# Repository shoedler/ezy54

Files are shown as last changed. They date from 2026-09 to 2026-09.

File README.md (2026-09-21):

> [!CAUTION]
> This is a WIP - this keyboard has not been built yet.

# ezy54
A 54-key, column-staggered, ortholinear, wireless split keyboard, inspired by ZSA Voyager and totem.
Designed for Choc-spacing (18mm horizontal, 17mm vertical) and 1350 Choc v1 or v2 switches.

---

## Bill of materials

For one complete board - e.g. two halves - you'll need:

- 2 Promicro NRF52840
- 54 1N4148W SOD-123 Diodes
- 54 Kailh Low-profile 1350 Hotswap Sockets
- 54 Keyswitches, Choc v1 or v2
- 54 Choc-spaced Keycaps, Choc v1 or v2 stems
- 2 EVQPUL02K Switches ($\to$ board reset button)
- 2 SSSS811101 Switches ($\to$ power switch)
- 2 701535 3.7v, 350mAh
- 2 JST PH 2.0 THT Sockets

For the case you'll need:

- Obviously, the printed case files. See section about printing below.
- 10x M2x5 (or 6)mm flathead screws
- 10x M2x3mm Heat set inserts
- Optionally, some painters tape.

## Build guide

### PCB manufacturing

> PCB related files are located in the `kicad` directory.

Assuming you have ordered the parts and don't want to route the PCB yourself, there's premade gerber archive located at `kicad/gerber.zip` which you can use. I've used JLCPCB, default settings (1.6mm two layer PCB) and with the black solder mask.

### Printing the case

> Case files are located in the `stl` directory.

I used a Babulab A1 mini and default slicer settings (Bambustudio). Everything was printed in their PLA Matte.

#### What do I need to print?

You'll need at least:

- 2x `ezy54_switchplate_right.stl`, which is the plate that sits on the PCB and where the keyswitches are mounted into - I recommend using the provided 3mf files for that: `ezy54_switchplate_left.3mf` and `ezy54_switchplate_right.3mf`. That'll give you mirrored versions so you have the buildplate-finish texture on the same side for both halves.
- 2x `ezy54_case_left.stl`, which is the case where the PCB gets mounted in - same story, use the provided 3mf files for that: `ezy54_case_left.3mf` and `ezy54_case_right.3mf`. That'll also give you mirrored versions for both halves with fuzzy skin. Theoretically, you don't **need** the case, but I strongly recommend it to provide a little bit of protection for the PCB. If you're working directly with the stl, then you'll have to mirror it. I suggest using the fuzzy skin setting (in Bambustudio: `Others > Special mode > Fuzzy skin`, use "Contour").

Optional:

- 2x `ezy54_case_cover_right.stl`, which is a small cover for the MCU + battery. Use `ezy54_case_cover_left.3mf` and `ezy54_case_cover_right.3mf` for mirrored version. Same as with the case, if you're working with the stl directly you'll need to mirror this too.
- 1x `ezy54_carry_case.stl`, which is a Go60-ish carry shell for the ezy54. Use `ezy54_carry_case.3mf` for a version with fuzzy skin. I did manage to print it without support, but there's a bit of luck involved.

### Soldering

Since the PCB is reversible it can get confusing quick. All of the components **except the ProMicro and the JST connector** are soldered to the backside of each half.

1. Solder diodes, hotswap sockets, reset- and powerswitches on the backside of each half. **This is also the side were you bridge all of the solder-jumpers with solder** (8 for the Mcu, 2 for the Battery connector).
2. Direct-solder the ProMicro to the frontside of the PCB, along with the JST connector. (Pin Sockets are also an option for the mcu, if you want - it just makes the keyboard a bit thicker)

> [!CAUTION]
> Before you continue it's a good idea to verify that there's no short between the JSTs +/- terminal as well as the ProMicros VCC and GND.

I suggest to load the firmware next and check that everything works before assembly.

### Loading the ZMK firmware

> Firmware related files consist of: config/, boards/, zephyr/ directories, as well as the build.yml file and the GitHub Actions workflow in .github/workflows.build.yml

Get the latest firmware from https://github.com/shoelder/ezy54/actions, select the latest run and scroll down to Artifacts - you'll be able to download the zip archive from there.

> [!NOTE]
> There'll be two .uf2 files per half in the zip archive - a `de-ch` and an `en` version. This refers to the keycode locale that's been used. I myself require a swiss locale, but, to make the default firmware more useful for more people, I've added an english version too. You can check the keymaps out in the `config/boards/shields/ezy54` directory.

For each half:

1. Plug in the half to your device using a USB cable.
2. Press the reset button twice within 500ms - on my versions of the ProMicro, their red LED breaths gently once you've entered bootloader mode.
3. You'll see a `NICENANO` appear in your device tree. Simply drag and drop the **correct** firmware for the half your working on onto the mcu - it should eject itself automatically once the firmware is flashed.

> [!NOTE]
> If you run into trouble, there's also a `settings_reset` firmware provided in the archive. See [the ZMK troubleshooting guide](https://zmk.dev/docs/troubleshooting/connection-issues#reset-split-keyboard-procedure) on how to flash it.

### Assembly

1. Prep the cases by installing the heat set inserts.
2. Cover the bottom sides of the PCBs with tape (I used masking tape). Apply the first layer quite firmly, such that it follows the contours of the hotswap sockets. You'll want to make sure that you extend the tape over the edges of the PCB. Apply at least 3 layers. In my experience anything beyond 5 layers of standard painters tape yields no further improvements. Also, it gets thick quick.
3. Trace the PCB outline to the tape with a pen. Also, trace the screw holes.
4. Remove the tape, and cut out the shape - make sure to inset the cut about 2-3mm, so the tape is not visible when everything is assembled. For the screw holes, cut a ~5x5mm square. Apply the tape.
5. Assemble both halves.
6. Install the switches, caps and the battery. For the battery, I usually use a thin, clear double-sided tape. Done!

---

## Modifying the ergogen config

The whole point of using ergogen, is to easily adapt the PCB to your liking. So give it a go!
Modifying the config will force you to reroute the PCB again. Though fear not - using [Freerouting](www.freerouting.app) this literally takes a minute to do (including adding freerouting to KiCad), provided you have KiCad >=8 and JRE >= 17 for Freerouting already installed.

> [!NOTE]
> To add the Freerouting KiCad integration, just follow [this](https://github.com/freerouting/freerouting/blob/master/docs/integrations.md) official guide.

> [!TIP]
> There is a local toolchain in [`tools/`](tools/README.md) that builds the config without
> ergogen.xyz and then checks it: case clearances, a pre-routing DRC on the generated board,
> STL/cross-section/point-probe inspection of the printed parts, and layered drawings. Start
> with `cd tools && npm run setup`, then `node tools/build.ts` and
> `node tools/drc-lite.ts out/pcbs/ezy54.kicad_pcb`. Its README also documents the
> footprint rotation convention that ergogen + KiCad make easy to get backwards.

1. Paste `config.yml` located in `/ergogen` into [ergogen.xyz](ergogen.xyz) and download the `ezy54.kicad_pcb` file.
2. Copy (and overwrite) `ezy54.kicad_pcb` to the `kicad` directory of this repository *(this part is only required if you intend to keep the source of this repository up to date - e.g. if you forked this)*
3. Open the PCB in KiCad (Standalone PCB editor suffices). Press `B` to fill the GND pours - zones come out of ergogen empty until KiCad calculates them once - then click on `Tools > External Plugins > Freerouting`
4. Let it rip. In my experience, the defaults of Freerouting suffice.

> [!IMPORTANT]
> Back in KiCad, run the DRC in `Inspect > Design Rule Checker`. I usually right click `> Ignore all 'Footprint not found in libraries' violations` to ignore missing ceoloide footprint warnings. This might leave you with some warnings which you need to manually resolve. For example, i usually get "Track has unconnected end", which is easily resolved by deleting the stub.

5. `File > Plot... > Generate Drill Files`, name the folder "gerber", then press `Generate` and close that popup. Press `Plot` back in the plot dialog. Done!

## References

- Flatfootfox' detailed design guide: https://flatfootfox.com/ergogen-part1-units-points/
- nickcoutsos Keymap-editor: https://nickcoutsos.github.io/keymap-editor/
- nickcoutsos Keymap-layout-tools: https://nickcoutsos.github.io/keymap-layout-tools/
- Joel Spadins zmk-locale-generator for the de-swiss keycode header: https://github.com/joelspadin/zmk-locale-generator
- ZMK guide on how to add a new shield: https://zmk.dev/docs/development/hardware-integration/new-shield
- More of my keyboards:
  - effiddy - a 50-key wireless split, inspired by totem: https://github.com/shoedler/effiddy
  - shoedler54 - a 54-key wireless split, inspired by ZSA Voyager and silakka54: https://github.com/shoedler/shoedler54

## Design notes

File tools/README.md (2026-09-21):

# ezy54 tooling

Local build + verification for `ergogen/config.yml`. The point is to be able to
change a unit and immediately see whether the PCB, the switchplate, the bottom
case and the carry case are all still sane — without pasting into ergogen.xyz
and eyeballing it.

Everything here is optional: the config is still a plain ergogen config you can
paste into <https://ergogen.xyz>.

## Setup

Needs **Node 22.18+** (for running TypeScript without a build step) and
**git**. Then:

```bash
cd tools && npm run setup
```

That installs the node dependencies and clones
[ceoloide/ergogen-footprints](https://github.com/ceoloide/ergogen-footprints)
into `tools/vendor/` (gitignored — it carries its own licence).

The tools are TypeScript and run directly: `node tools/check.ts`, no build, no
`dist/`. `npm --prefix tools run typecheck` runs `tsc --noEmit` over them, and
`npm --prefix tools test` runs the unit tests.

## Build

```bash
node tools/build.ts
```

Writes `out/` — `outlines/`, `cases/`, `pcbs/ezy54.kicad_pcb`, and (because it
runs ergogen in debug mode) `points/points.yaml` + `points/units.yaml`, which
every check below reads.

## Checks

### `node tools/check.ts out`

Geometric assertions on the case: that the MCU/battery housing is inside the
board outline, the cavity inside the housing, the screw bosses inside the
cavity, the battery and connector inside the cavity — plus the clearances that
matter (housing wall to nearest keycap, boss to battery, MCU to cavity wall),
the USB-C window's position against the receptacle, and the stack heights.

### `node tools/drc-lite.ts out/pcbs/ezy54.kicad_pcb`

A KiCad-free pre-flight on the generated board:

- copper too close to, or hanging off, the board edge
- pads of different nets too close together
- drilled holes too close to the board edge
- the GND pour still covering the board and the MCU keepout still covering the
  MCU — those two zone polygons are **literal coordinates** in the config
  (ergogen does not resolve unit names inside nested arrays), so nothing else
  keeps them in sync with the layout. Re-run this after moving anything in the
  MCU column.

Thresholds default to JLCPCB's (`--edge 0.3 --pad 0.2 --hole 0.5`).

It deliberately does **not** check courtyard overlaps: every switch overlaps its
own diode here, which is normal for a keyboard.

### `node tools/drc.ts` — the real thing

Runs `kicad-cli pcb drc` and summarises it. Needs KiCad 8+ on PATH. Run it on
the generated board before routing, and again on `kicad/ezy54.kicad_pcb` after.

On an unrouted board every net is reported as an unconnected item — that is
expected, look at the `violations` group.

### `npm --prefix tools test`

Unit tests over the geometry, the s-expression reader and the formatting, plus
the one regression test that has actually earned its keep — see "the rotation
gotcha" below. Run it whenever you touch `lib/geom.ts`.

### `node tools/diode-fit.ts`

Sweeps the diode anchor offset against every other pad and the board edge.
Only needed if the key layout changes.

## Cases

```bash
node tools/cases.ts
```

Evaluates each generated `.jscad` (they use the CSG v1 API) into `out/stl/`,
reporting bounds and volume — a negative or wildly wrong volume means the
booleans went bad.

`tools/jscad.ts` does one case at a time and can do more:

```bash
# cross sections through the housing, as an SVG
node tools/jscad.ts out/cases/ezy54_case_switchplate_right.jscad \
    --cut "x=263,y=-140,z=5" --svg out/section.svg --scale 6

# is there material at this point?
node tools/jscad.ts out/cases/ezy54_case_left.jscad \
    --probe "reset opening:238.1,-82.7,5;floor:240,-90,1"
```

`--probe` ray-casts the mesh and answers SOLID/empty per point. It is the
fastest way to confirm a wall, a lip or a cutout is really where you think.

## Drawings

```bash
node tools/render.ts out --o ezy54:#000:0.5 --o _shroud_outer:#f80:0.4 \
     --labels --grid 10 --scale 5 --out out/board.svg
node tools/svg2png.ts out/board.svg out/board.png 1400
```

`--o name[:colour[:width]]` layers any generated outline; `--points`/`--labels`
overlay the ergogen points; `--crop x0,y0,x1,y1` zooms in. Coordinates are
ergogen's (y up), matching `points.yaml`.

## Routing, after all this

1. `node tools/build.ts`, then `node tools/drc-lite.ts out/pcbs/ezy54.kicad_pcb`
   until it is clean.
2. Copy `out/pcbs/ezy54.kicad_pcb` over `kicad/ezy54.kicad_pcb`.
3. Open it in KiCad, press `B` to fill the zones (the pours come out empty
   until KiCad calculates them once).
4. `Tools > External Plugins > Freerouting`.
5. Back in KiCad: teardrops, then curvy tracks.
6. `node tools/drc.ts --pcb kicad/ezy54.kicad_pcb`.

## The rotation gotcha

Worth reading before you move a footprint, because it is silent and it cost a
PCB revision.

Ergogen works y-up and negates y when it writes the board. Footprint bodies,
though, are authored in KiCad's own y-down frame and placed with a rotation of
`key rotation + adjust.rotate`. To work out where a pad actually lands you need
KiCad's rotation convention, and it is the counter-intuitive one: angles are
counter-clockwise *as displayed*, and the file's y axis points down, so in file
coordinates a footprint-local offset is rotated by **minus** the angle:

```
x' =  x·cos(t) + y·sin(t)
y' = -x·sin(t) + y·cos(t)
```

Get that sign backwards and the y component of every footprint-internal offset
flips on any rotated footprint. The tooling did exactly that at first, and it
produced two confident, wrong conclusions:

- it said `rotate: 90` aimed the power switch's slider south into the board, so
  the config was changed to `-90`. It does not - `90` is correct, and `-90` is
  what actually pointed it the wrong way.
- it said diode pads on the splayed thumb keys collided with the switch's
  plated centre hole, which led to an unnecessary `pcb_diode_x_off`.

With the correct convention there is no dependence on the key's rotation at
all. Substituting `R = r + A` into the two transforms gives a footprint-local
offset, expressed in its own key's frame, of

```
Lx = lx·cos(A) + ly·sin(A)
Ly = lx·sin(A) - ly·cos(A)
```

— only `adjust.rotate` appears. A footprint's geometry sits in the same place
relative to every key, however splayed.

`lib/geom.ts` has the two conventions side by side as `rotateKicad` (this one)
and `rotateCcw` (ergogen's own y-up frame); confusing them is the mistake.
`test/rotation.test.ts` pins it down: it compares the computed hole positions
against the Excellon coordinates KiCad itself produced, read out of the
committed `kicad/gerber.zip`. Correct convention matches to 0.0005mm; the wrong
one misses 4 of 10 holes by up to 0.154mm. Run `npm --prefix tools test` after
touching `rotateKicad`.

What *did* survive the correction: the reset and power switches genuinely need
`sw_reset_y_in` / `sw_power_y_in` around 2.3 / 2.2. At the original 1.75 / 1.25
the power switch's mounting pads cross the board edge and the reset switch's
mounting boss sits exactly on it, whichever convention you use.

## Layout

| | |
|---|---|
| `build.ts` | ergogen config → `out/` |
| `cases.ts` | every `.jscad` → `out/stl/` |
| `jscad.ts` | one `.jscad`: stats, STL, probes, sections |
| `check.ts` | geometric assertions on the case |
| `drc-lite.ts` | KiCad-free pre-flight on the board |
| `drc.ts` | `kicad-cli` DRC, summarised |
| `diode-fit.ts` | diode anchor offset sweep |
| `render.ts` | outlines + points → SVG |
| `svg2png.ts` | SVG → PNG |
| `fetch-footprints.ts` | clone/update the vendored footprint library |
| `lib/` | the shared core: CLI parsing, formatting, geometry, KiCad and outline models, the JSCAD runtime |
| `test/` | `node --test` unit tests |
| `vendor/` | third-party, gitignored, do not edit |

One thing in `lib/` looks stranger than it is: `fmt.ts` reimplements Python's
number formatting and `geom.ts` has its own `hypot`. These tools were ported
from Python, and their output is diffed against the originals; `toFixed` and
`Math.hypot` each disagree with Python often enough to change a printed digit
or reorder two tied rows. Both are commented and tested.

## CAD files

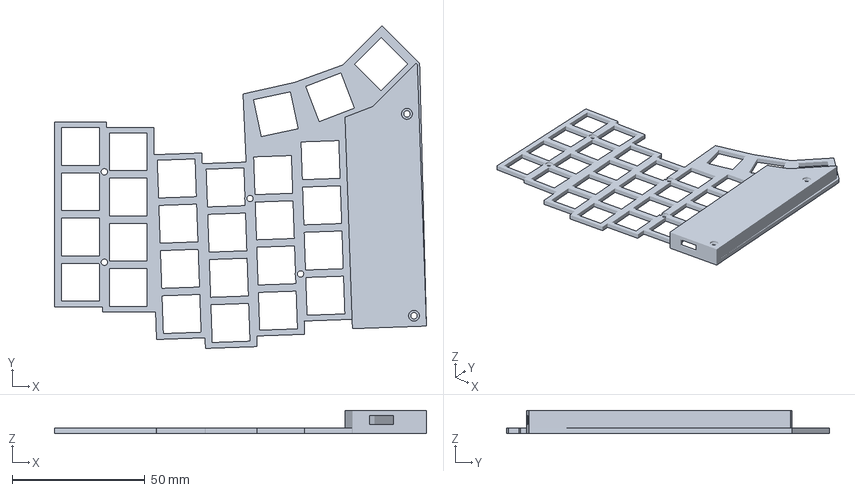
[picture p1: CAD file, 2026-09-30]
stl/ezy54_case_switchplate_right.3mf
139.9 x 121.4 x 8.80 mm

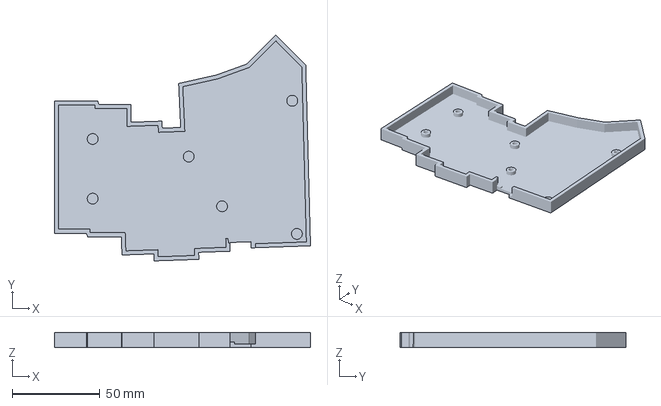
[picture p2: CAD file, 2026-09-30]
stl/ezy54_case_right.3mf
146.0 x 128.8 x 8.30 mm

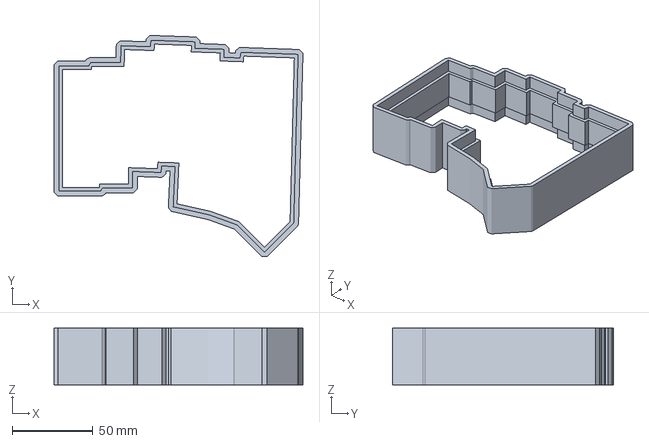
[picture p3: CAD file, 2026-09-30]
stl/ezy54_carry_case.3mf
154.0 x 136.8 x 35.0 mm

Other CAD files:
stl/ezy54_case_switchplate_left.3mf
stl/ezy54_case_left.3mf
stl/ezy54_carry_case.stl
stl/ezy54_case_left.stl
stl/ezy54_case_switchplate_right.stl

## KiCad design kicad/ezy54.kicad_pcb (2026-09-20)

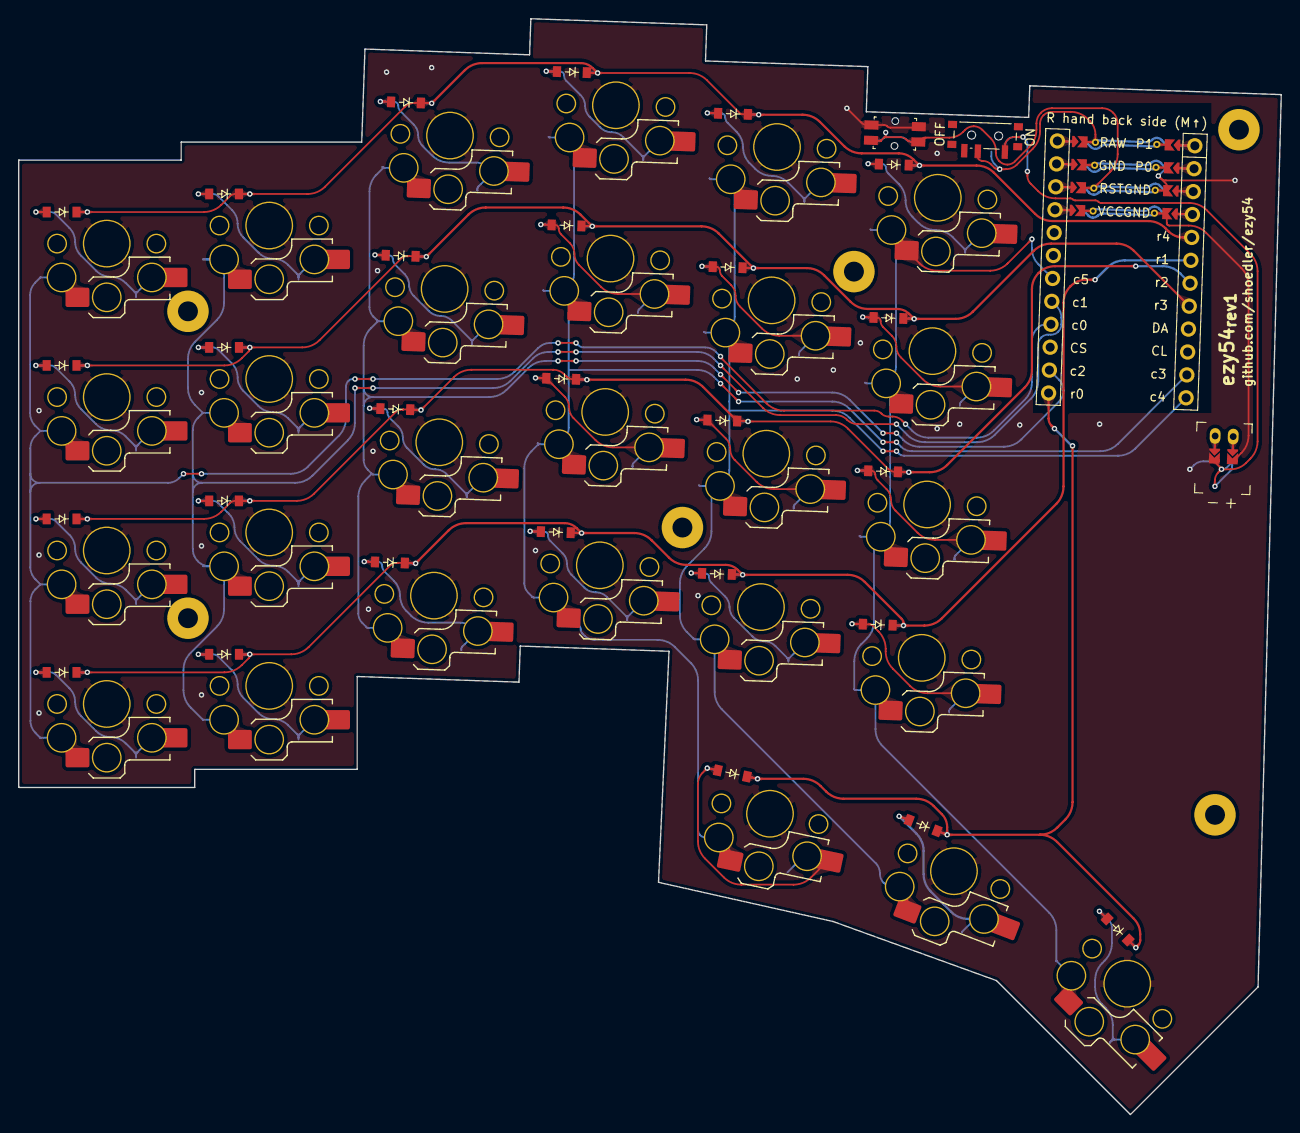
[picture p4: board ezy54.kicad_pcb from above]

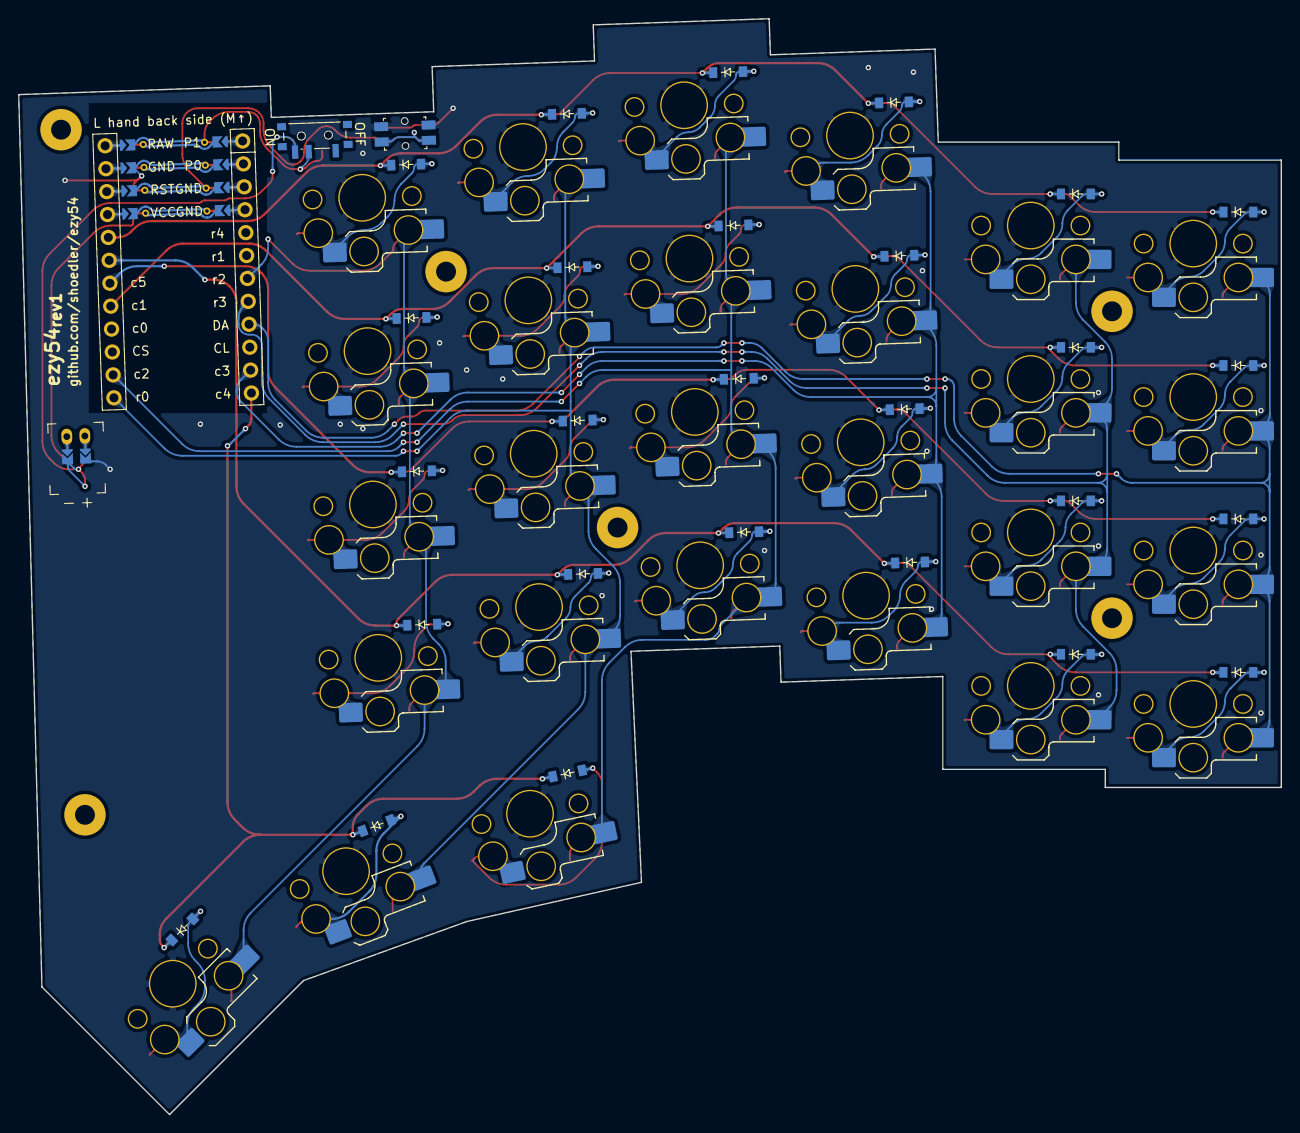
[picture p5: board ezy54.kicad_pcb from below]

Board: 2 copper layers, 139.9 x 121.4 mm, 64 parts (27 on the bottom side), 44 nets.

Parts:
D1, D2, D3, D4, D5, D6, D7, D8, D9, D10, D11, D12, D13, D14, D15, D16, D17, D18, D19, D20, D21, D22, D23, D24, D25, D26, D27: diode_tht_sod123
JST1: battery_connector_jst_ph_2
MCU1: mcu_supermini_nrf52840
MH1, MH2, MH3, MH4, MH5, MH6: mounting_hole_npth
PWR1: power_switch_smd_side
RST1: reset_switch_smd_side
S1, S2, S3, S4, S5, S6, S7, S8, S9, S10, S11, S12, S13, S14, S15, S16, S17, S18, S19, S20, S21, S22, S23, S24, S25, S26, S27: switch_choc_v1_v2

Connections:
BAT_P: JST1.1, PWR1.1, PWR1.3
GND: JST1.2, MCU1.103, MCU1.104, MCU1.123, RST1.1, RST1.3
JST1_1: JST1.11, JST1.21, JST1.31
JST1_2: JST1.12, JST1.22, JST1.32
RAW: MCU1.124, PWR1.2
RST: MCU1.122, RST1.2, RST1.4
c0: MCU1.16, S1.2, S2.2, S3.2, S4.2
c0_r1: D1.2, S1.1
c0_r2: D2.2, S2.1
c0_r3: D3.2, S3.1
c0_r4: D4.2, S4.1
c1: MCU1.17, S5.2, S6.2, S7.2, S8.2
c1_r1: D5.2, S5.1
c1_r2: D6.2, S6.1
c1_r3: D7.2, S7.1
c1_r4: D8.2, S8.1
c2: MCU1.14, S9.2, S10.2, S11.2, S12.2
c2_r1: D9.2, S9.1
c2_r2: D10.2, S10.1
c2_r3: D11.2, S11.1
c2_r4: D12.2, S12.1
c3: MCU1.11, S13.2, S14.2, S15.2, S16.2, S25.2
c3_r0: D25.2, S25.1
c3_r1: D13.2, S13.1
c3_r2: D14.2, S14.1
c3_r3: D15.2, S15.1
c3_r4: D16.2, S16.1
c4: MCU1.12, S17.2, S18.2, S19.2, S20.2, S26.2
c4_r0: D26.2, S26.1
c4_r1: D17.2, S17.1
c4_r2: D18.2, S18.1
c4_r3: D19.2, S19.1
c4_r4: D20.2, S20.1
c5: MCU1.18, S21.2, S22.2, S23.2, S24.2, S27.2
c5_r0: D27.2, S27.1
c5_r1: D21.2, S21.1
c5_r2: D22.2, S22.1
c5_r3: D23.2, S23.1
c5_r4: D24.2, S24.1
r0: D25.1, D26.1, D27.1, MCU1.13
r1: D1.1, D5.1, D9.1, D13.1, D17.1, D21.1, MCU1.6
r2: D2.1, D6.1, D10.1, D14.1, D18.1, D22.1, MCU1.7
r3: D3.1, D7.1, D11.1, D15.1, D19.1, D23.1, MCU1.8
r4: D4.1, D8.1, D12.1, D16.1, D20.1, D24.1, MCU1.5

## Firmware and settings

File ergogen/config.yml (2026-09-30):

meta:
  engine: 4.2.1

# =====================================================================
#  ezy54 - 54 key column staggered wireless split, Choc v1/v2, 18x17mm
#
#  Everything that has a physical meaning lives in `units` below. The
#  markup only ever refers to units, so changing a number here
#  propagates to the PCB, the switchplate (incl. the MCU/battery
#  housing), the bottom case and the carry case at once.
# =====================================================================

units:
  # ------------------------------------------------------------------
  #  PCB / fabrication
  # ------------------------------------------------------------------
  pcb_t: 1.6 # 2 layer JLCPCB default
  pcb_edge_pad: 1.5 # Copper-free margin the outline adds around a key
  pcb_origin_x: 150 # Keeps KiCad coordinates positive
  pcb_origin_y: -150
  pcb_screw_hole_size: 4.6 # NPTH annulus for the M2 clearance hole
  pcb_screw_drill: 2.2
  pcb_switch_pad_w: 2 # Outer hotswap pad width
  # Diode placement relative to its switch.
  #
  # The x offset is not actually required: the original [0, 3.5] passes
  # `node tools/drc-lite.ts` too. It was added in response to a phantom
  # collision on the splayed thumb keys, which turned out to be a rotation
  # sign bug in the tooling (see tools/README.md). It is kept because pcb
  # rev1 was fabricated with it - revert to 0 for a future revision if you
  # would rather have the shorter traces. tools/diode-fit.ts sweeps the offset
  # against every other pad and the board edge.
  pcb_diode_x_off: -5
  pcb_diode_y_off: 3.5
  pcb_clearance: 0.2 # JLCPCB minimum copper to copper
  pcb_edge_clearance: 0.3 # JLCPCB minimum copper to board edge

  # ------------------------------------------------------------------
  #  Copper pours
  #
  #  A GND pour on both layers, with the MCU footprint cut out of it: the
  #  nice!nano v2 / SuperMini guidance is to keep copper from under the
  #  module so its antenna is not detuned.
  #
  #  Zone polygons are written into the board verbatim, so unlike every
  #  other number here they are *KiCad* coordinates - y points down, the
  #  negation of ergogen's y - and they have to be literals, because
  #  ergogen does not resolve unit names inside nested arrays. They live
  #  next to the footprints in `pcbs:`. They are not derived, so
  #  `node tools/drc-lite.ts` asserts that the pour still covers the
  #  board and the keepout still covers the MCU. Re-run it if you move
  #  anything in the MCU column.
  # ------------------------------------------------------------------
  # ------------------------------------------------------------------
  #  Key layout  (verified ergonomics - touch with care)
  #  cx / cy are ergogen's cap units: 18 x 17 mm.
  # ------------------------------------------------------------------
  key_c1_stagger: 2 # Pinky
  key_c2_stagger: 10 # Ring
  key_c2_splay: -2
  key_c3_stagger: 4 # Middle
  key_c4_stagger: -4 # Index
  key_c5_stagger: -5 # Inner
  key_mid_spread: cx + 0.25 # Ring + middle get a hair more spread

  thumb_anchor_x: -0.9 * cx
  thumb_anchor_y: -1.05 * cy
  thumb_spread: 20
  thumb_c3_splay: -10
  thumb_c4_splay: -9
  thumb_c5_splay: -24
  thumb_c4_origin_x: -12
  thumb_c4_origin_y: -9
  thumb_c5_origin_x: -10
  thumb_c5_origin_y: -8

  keycap_gap: 0.5 # Air between neighbouring 1u caps
  keycap_fillet: 1
  keycap_w: cx - keycap_gap
  keycap_d: cy - keycap_gap
  keycap_h: 10.7 # PCB top -> top of switch+cap (measured on shoedler54)

  # ------------------------------------------------------------------
  #  MCU - SuperMini nRF52840 on a removable socket
  #
  #  The male header is soldered in from the top, its plastic removed
  #  and the pins cut flush, so nothing sticks up past the board. The
  #  USB-C shell is therefore the tallest part of the assembly, and it
  #  is let into the MCU's own pcb - its underside is flush with the
  #  underside of the MCU board, i.e. exactly one socket height up.
  # ------------------------------------------------------------------
  mcu_w: 17.78
  mcu_h: 33
  mcu_socket_h: 3.6 # Female pin header the MCU seats on
  mcu_usb_w: 8.94 # USB-C receptacle, across the board
  mcu_usb_d: 7.35 # USB-C receptacle, along the board
  mcu_usb_t: 3.2 # USB-C receptacle height
  mcu_usb_inset: 0.7 # Receptacle overhang past the MCU board edge
  mcu_usb_z: mcu_socket_h # Underside of the receptacle, above the PCB
  mcu_top_h: mcu_usb_z + mcu_usb_t # Tallest point of the assembly
  mcu_north_keepout: mcu_h / 2 + mcu_usb_inset # Board edge, or the USB-C shell
  mcu_col_gap: 0.75 # Keycap edge -> housing outer wall, everywhere
  # The MCU column's north edge may run ahead of the key field's: columns
  # c3/c4 sit further north anyway, so this is free board area. Measured
  # from the key field's north edge to the outside of the north wall.
  mcu_col_north_off: 3.5
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

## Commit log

2026-07-27 Adds initial commit - see ergogen/config.yml for open TODOs
    [ezy54.kicad_pcb, ezy54_carry_case.3mf, ezy54_carry_case.stl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]
2026-07-27 Fixes thumbcluster spike and columns gaps
    [config.yml]
2026-07-27 Fixes i/o cutouts, fixes screw positions
    [config.yml]
2026-07-27 Adds bat wire cutout
2026-09-18 Adds local build/verification tooling, GND pours, fixes DRC violations
    Tooling in tools/ (see tools/README.md): builds ergogen/config.yml without
    ergogen.xyz, then checks the result. drc_lite.py is a KiCad-free pre-flight
    on the generated board; drc.js wraps kicad-cli for the real thing; check.py
    asserts the case geometry; jscad_run.js evaluates the .jscad cases into STLs,
    cross sections and point probes.
    PCB:
    - GND pour on both layers, with a keepout over the MCU footprint so the
    module's antenna is not detuned (nice!nano v2 guidance). The zone polygons
    have to be literal KiCad coordinates - ergogen does not resolve unit names
    inside nested arrays - so drc_lite.py asserts they still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
    [config.yml]
2026-09-20 Adds pcb rev1 files
    [ezy54.kicad_pcb, temp-freerouting.dsn]
2026-09-21 Flips the power switch back to rotate: 90
    rotate: -90 aimed the slider's actuator south, into the board. 90 is
    correct and is what pcb rev1 was fabricated with, so the config now
    matches the board again.
    [config.yml]
2026-09-21 Fixes the footprint rotation convention in drc_lite
    KiCad footprint and pad angles are counter-clockwise as displayed, and the
    file's y axis points down, so rotating a footprint-local offset into board
    coordinates is a rotation by minus the angle. drc_lite.rot() had the sign the
    other way round, which flipped the y component of every footprint-internal
    offset on any rotated footprint.
    That produced two confident but wrong results earlier:
    - it reported that rotate: 90 aimed the power switch's slider south, which is
    what led to the -90 reverted in the previous commit
    - it reported diode pads colliding with the switch's plated centre hole on the
    splayed thumb keys, which is why pcb_diode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
    [config.yml]
2026-09-21 Rewrites the tooling in TypeScript and drops Python
    The nine scripts in tools/ had grown into a mix of Python and JavaScript
    that duplicated geometry between check.py and drc_lite.py, reimplemented
    argument parsing four times, and passed geometry around as positional
    tuples indexed as s[4].
    They are now one TypeScript toolchain over a shared lib/: CLI parsing,
    formatting, geometry, s-expression and KiCad models, outline walking and
    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
2026-09-30 Updates case files and 3mf files.
    [ezy54_carry_case.3mf, ezy54_case_cover_left.3mf, ezy54_case_cover_right.3mf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]
2026-09-30 Updates stls
    [ezy54_carry_case.stl, ezy54_case_cover_right.stl, ezy54_case_left.stl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]
2026-10-11 Enhance README with images and assembly instructions
    Updated README to include additional images, improved instructions, and clarified assembly steps.
